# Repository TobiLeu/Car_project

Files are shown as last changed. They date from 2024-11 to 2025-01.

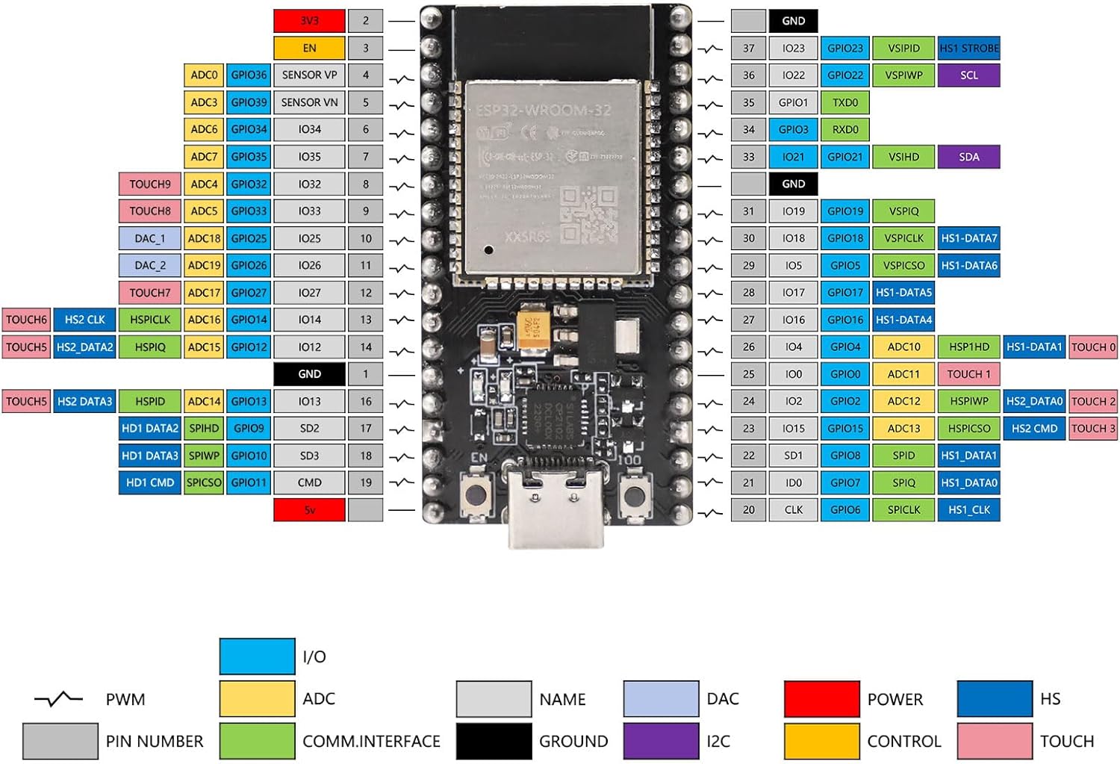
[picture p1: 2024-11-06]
Datenblätter/ESP32_Pinout.jpg

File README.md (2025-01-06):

Bei diesem Repository handelt es sich um ein Projekt für ein ferngesteuertes Auto:

Ein Video des Fahrzeugs ist im Repository vorhanden.
Programmierung ist mit Micropython erfolgt.
Es wurde ein Bausatz eines Kettenlaufwerks verwendet. Stattdessen kann mit dem Code im Repository auch ein Fahrzeug verwendet werden, das über Einzelansteuerung des beiden Fahrzeugseiten lenkt.

Beschreibung:

Auto:
Es wurde ein Bausatz eines Kettenlaufwerks verwendet, im Internet unter den Namen T101 oder TP101 zu finden. Ein Datenblatt für den Bausatz ist nicht erhältlich.
Der verwendete Bausatz hat 2 12V DC Motoren. Diese werden über eine H-Brücke versorgt. Als Batterie wurden alte Lithium Akkus verwendet.
Die Karosserie wurde mit einem 3D-Drucker hergestellt, Modell im Repository.
Es wurde ein ESP32 verwendet. Dieser steuert das Auto und erhält die Steuersignale von einem zweiten ESP32 im Controller, das ESPNow Modul wurde für die Datenübertragung verwendet.
Die Beleuchtung des Autos erfolgt mit LED's, die über den Controller an bzw. ausschaltbar sind.

Controller:
Der Controller für die Fernsteuerung wurde selbst gebaut. Hierzu wurde eine Abzweigdose verwendet, in die ein ESP32 eingebaut wurde. Der ESP32 wird mit einer 5V-Powerbank versorgt.
Der Controller hat 2 Joysticks mit Tasterfunktion, die je eine Kette des Fahrzeugs steuern. Die Tasterfunktion eines Joysticks wird für die An-/Ausschaltung des Fahrzeuglichts verwendet.
Zusätzlich ist im Controller ein 5V LCD-Display verbaut worden, Datenblatt nicht vorhanden. Das Display die Geschwindigkeit jeder einzelnen Kette in Prozent an.
Ein Start des Controllers führt zum Reset des Microcontrollers des Autos.

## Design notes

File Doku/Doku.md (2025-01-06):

# Dokumentation <TEAMNAME>

**Mitglieder:**
- Annika Hoffmanns
- Christian Löhner
- Tobias Leuthel

## Woche 1 (28.10- 03.11.2024)

### Aktivitäten:
- Zusammenbauen des Kettenradsatzes, Austesten an 9V Batterieblock

### Probleme und Lösungen:
- ChatGPT ist nicht hilfreich. Konkretere prompts sind nötig.

### Code:
- Siehe git history.

### Quellen:

## Woche 2 ( 04. - 10.11.2024)

### Aktivitäten:
- Informationen über ESP Now gesammelt
 - Mac Adressen ausgelesen (Annika) 
-   1: MAC-Adresse des ESP32: 88:13:bf:6f:c1:9c   (Controller - Sender) 
-   2: MAC-Adresse des ESP32: ac:15:18:e9:8c:7c   (Reserve ESP)
-   3: MAC-Adresse des ESP32: 88:13:bf:6f:b9:bc   (Auto - Empfänger) 

 - ESP 32 Treiber heruntergeladen und geflasht (Tobi) 
 - Funktion für die Vorwärtsfahrt erstellt (Christian) 

### Quellen:
 - https://wolles-elektronikkiste.de/esp-now    ( Auslesen der Mac-Adresse) 

## Woche 3 ( 11. - 17.11.2024)

### Aktivitäten:
- Informationen über ESP Now gesammelt (Tobi)
    -Chat GPT über biderektionale Verbindung zweier ESP's gefragt:
    - Probleme: esp.init() wird nicht gefunden
                OSError wird gemeldet: OSError: (-12389, 'ESP_ERR_ESPNOW_NOT_INIT')
                bisher noch keine Lösung gefunden

- Code für Fahrfunktionen schreiben (Chris)
 -Joysticks auf den ESP Auto montiert (Annika)
 -Fahrbetrieb getestet (Annika, Chris)
 -Verdrahtung Auto (Annika)
 
-Über Schaltplanzeichnen informiert (Chris)

### Quellen:
 - https://chatgpt.com/g/g-cKXjWStaE-python/c/6719f789-da14-800c-9771-9de5a383086b ; Link Chatgpt
 - https://docs.micropython.org/en/latest/library/espnow.html

## Woche 4 ( 18. - 24.11.2024)

### Aktivitäten:
- Code für Controller geschrieben und angepasst (Tobi, Annika)
    -Umwandlung von Byte-Signal
    -Codevorlage von mycropython.org angepasst

- Code Fahrfunktion überarbeitet (Chris, Tobi):
    -lineare Transformation Probleme behoben
    -Umwandlung vom Sendersignal von 16 bit auf 10 bit von Chat GPT Funktion schreiben lassen

- Abzweigdose für Controller vorbereitet (Annika)

 -Fahrbetrieb getestet (Annika, Chris, Tobi)

### Quellen:
 - https://chatgpt.com/g/g-cKXjWStaE-python/c/6719f789-da14-800c-9771-9de5a383086b
 - https://docs.micropython.org/en/latest/library/espnow.html

## Woche 5 ( 25.11 - 01.12.2024)

### Aktivitäten:
- Controller
    - Öffnungen mit Dremel ausfräsen (Annika)
    - Displayhalterung gedruckt (Chris)
    - Controller bis auf Ein-/Ausschalter mechanisch fertiggestellt (Annika)

- Code Auto (Tobi)
    -Sendefunktion überarbeitet: 
        Problem, dass Steuerung nicht funktioniert, wenn der Controller nach dem Auto eingeschaltet wird
        Lösung: reboot Befehl an Auto ESP senden, wenn der Controller ESP eingeschaltet wird
    
- Code Controller (Annika)
    - Tasterbefehl einlesen und an Auto senden

- Spannungsversorgung Auto, mit Festspannungsregler; 2x 9V Blöcke in Reihe auf 12V regeln (Chris)
    - Die 9 V Blöcke, aufladbar per USB-C, haben eine Laderegelung, die abschaltet. -> 9V NiMh Akkus verwenden

- Schaltung für LED's Autobeleuchtung (Tobi)
    - LED's direkt über den ESP ansteuern: hat nicht funktioniert, vermutlich zu viel Strom -> extra Schaltung nötig

### Quellen:
 LED Flussspannungen: https://www.mikrocontroller.net/articles/LED#Flu%C3%9Fspannung

## Woche 6 ( 02.12 - 08.12.2024)

### Aktivitäten:

- Code Auto (Chris)
    - Pinout für Beleuchtung programmiert
    
- Controller (Annika)
    - Taster verdrahtet

- Spannungsversorgung (Chris, Annika):
    - Controller: Senden funktioniert nicht mit 3,3V -> 5V Powerbank verwenden
    - 24V Batterieblock demontiert und einzelne Zellen verwenden (14V)

- Schaltung für LED's Autobeleuchtung (Tobi)
    - Schaltung berechnet, verdrahtet und getestet

### Quellen:
 LED Flussspannungen: https://www.mikrocontroller.net/articles/LED#Flu%C3%9Fspannung

## Woche 7 ( 09.12 - 15.12.2024)

### Aktivitäten:
    
- Controller
    - Code für das LCD Display geschrieben: Umrechnungsfunktionen von Code Auto benutzt (Tobi)
    - Ein/Aus Schalter eingebaut (Annika)

- Hardware Auto auf Lochrasterplatine gelötet (Chris)

- Karosserie gedruckt (Chris)

### Quellen:
 https://chatgpt.com/g/g-cKXjWStaE-python/c/6719f789-da14-800c-9771-9de5a383086b
 Link Modell T1 Bus: https://www.printables.com/model/35314-modular-vw-bus-container

## Woche 8 ( 16.12 - 22.12.2024)

### Aktivitäten:
    
- Controller 
    - Hardware auf Lochrasterplatine löten (Chris)
    - Display einbinden (Chris, Tobi, Annika)

- Karosserie:
    - Einbau der LED's und Magnete für Dachhalterung (Annika, Chris)
    - Aufkleber drucken + bekleben (Annika)

### Quellen:
https://chatgpt.com/g/g-cKXjWStaE-python/c/6719f789-da14-800c-9771-9de5a383086b

## Woche 9 + 10 ( 23.12.2024 - 05.01.2025)

### Aktivitäten:
    
- Videodreh (Annika)

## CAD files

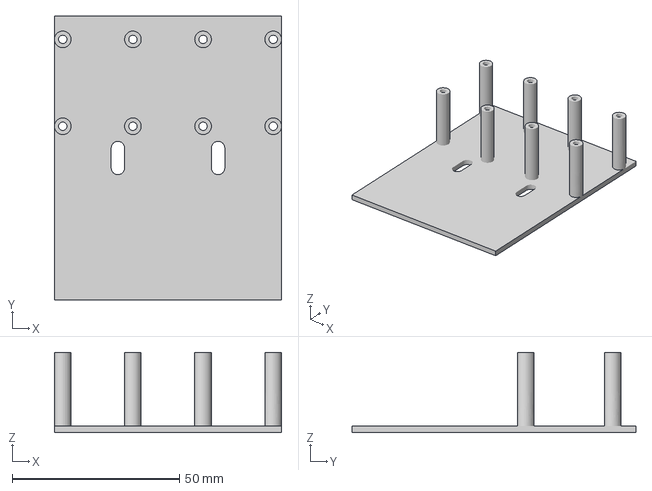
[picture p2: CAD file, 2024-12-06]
Datenblätter/Grundplatte.3mf
68.0 x 85.0 x 24.0 mm

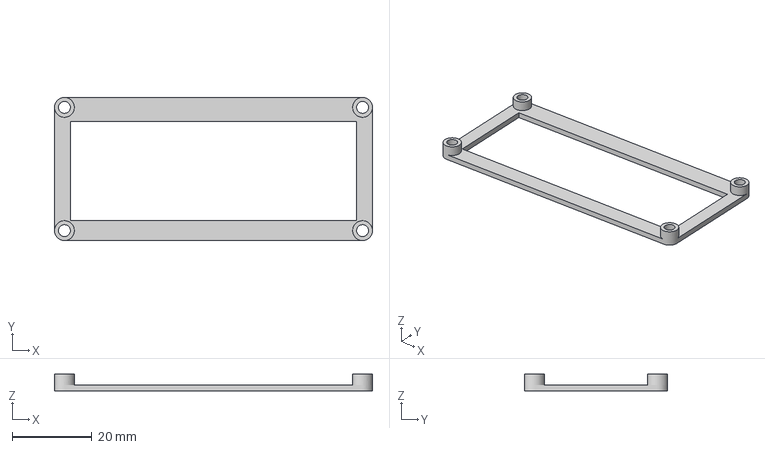
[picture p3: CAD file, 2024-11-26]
Datenblätter/Halterung.3mf
80.0 x 36.0 x 4.20 mm

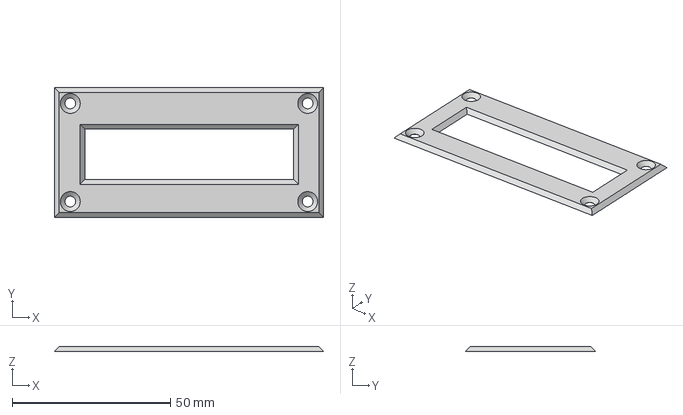
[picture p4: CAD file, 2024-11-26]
Datenblätter/Abdeckung.3mf
85.0 x 41.0 x 1.50 mm

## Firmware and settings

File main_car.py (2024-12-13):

from machine import Pin, ADC, PWM
import machine
import time
import network 
import espnow


# MAC-Adresse des ESP32: 88:13:bf:6f:b9:bc

#Setup PINS

motor_1_IN1 = Pin(22, Pin.OUT)
motor_1_IN2 = Pin(23, Pin.OUT)
motor_1_pwm = PWM(Pin(32), freq=250, duty=0)
motor_2_IN3 = Pin(27, Pin.OUT)
motor_2_IN4 = Pin(14, Pin.OUT)
motor_2_pwm = PWM(Pin(12), freq=250, duty = 0)
light = Pin(15, Pin.OUT)

#Setup WLAN
wlan = network.WLAN(network.STA_IF)
wlan.active(True)
wlan.disconnect()   # Because ESP8266 auto-connects to last Access Point

#ESP Now Setup
e = espnow.ESPNow()
e.active(True)

#ADC 
death_zone_upper_limit = 530
death_zone_lower_limt = 400
pwm_start = 256
pwm_end = 1023




# 16bit Eingang zu 10 bit konvertieren
def convert_16bit_to_10bit(value_16bit):
    
    if not (0 <= value_16bit <= 65535):
        raise ValueError("Die Eingabewert muss zwischen 0 und 65535 liegen.")
    
    # Skalieren des 16-Bit-Wertes in den Bereich einer 10-Bit-Zahl
    value_10bit = int((value_16bit / 65535) * 1023)
    
    return value_10bit


# PWM signal for forward drive
def map_range_forward(value, in_min, in_max, out_min, out_max):
    """
    Rechnet einen Wert aus einem Bereich in einen anderen Bereich um.

    :param value: Der Eingabewert, der umgerechnet werden soll.
    :param in_min: Untere Grenze des Eingabebereichs.
    :param in_max: Obere Grenze des Eingabebereichs.
    :param out_min: Untere Grenze des Zielbereichs.
    :param out_max: Obere Grenze des Zielbereichs.
    :return: Der umgerechnete Wert im Zielbereich.
    """
    return (value - in_min) * (out_max - out_min) // (in_max - in_min) + out_min



def map_range_backward(value, in_min, in_max, out_min, out_max):
    """
    Rechnet einen Wert aus einem Bereich in einen anderen Bereich um.
    :param value: Der Eingabewert, der umgerechnet werden soll.
    :param in_min: Untere Grenze des Eingabebereichs.
    :param in_max: Obere Grenze des Eingabebereichs.
    :param out_min: Untere Grenze des Zielbereichs.
    :param out_max: Obere Grenze des Zielbereichs.
    :return: Der umgerechnete Wert im Zielbereich.
    """
    return (value - in_min) * (out_max - out_min) // (in_max - in_min) + out_min


def left_track (analog_In_l):
    if analog_In_l > death_zone_upper_limit :
        motor_1_IN1.on()
        motor_1_IN2.off()
        motor_1_pwm.duty(map_range_forward(analog_In_l, death_zone_upper_limit, 1023, pwm_start, pwm_end))
    
    elif analog_In_l < death_zone_lower_limt :
        motor_1_IN1.off()  
        motor_1_IN2.on()
        motor_1_pwm.duty(map_range_backward(analog_In_l,death_zone_lower_limt, 0, pwm_start, pwm_end))
    
    else:
        motor_1_IN1.off()
        motor_1_IN2.off()
        motor_1_pwm.duty(0)

# Steuerung rechte Kette

def right_track(analog_In_r):
    if analog_In_r > death_zone_upper_limit:
        motor_2_IN3.on()
        motor_2_IN4.off()
        motor_2_pwm.duty(map_range_forward(analog_In_r, death_zone_upper_limit, 1023, pwm_start, pwm_end))

    elif analog_In_r < death_zone_lower_limt :
        motor_2_IN3.off()  
        motor_2_IN4.on()
        motor_2_pwm.duty(map_range_backward(analog_In_r, death_zone_lower_limt, 0, pwm_start, pwm_end))
    
    else:
        motor_2_IN3.off()
        motor_2_IN4.off()
        motor_2_pwm.duty(0)

# Hauptschleife  
while True:
    host, msg = e.recv()
    if msg:  #msg == None if timeout in recv()
        print(msg)
        msg =str(msg)
        msg = msg.lstrip("b'")
        msg = msg.rstrip("'")
        values = msg.split(",")
        value1 = int(values[0])
        value2 = int(values[1])
        value3 = int(values[2])
        value4 = int(values[3])
        value1 = convert_16bit_to_10bit(value1)
        value2 = convert_16bit_to_10bit(value2)

        if value3 == 1:
            print("rebooting")
            machine.reset()
            
        if value4 == 1:
            print("light")
            light.on()
        else:
            light.off()

        left_track(value1)
        right_track(value2)
        time.sleep(0.001)

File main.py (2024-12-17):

import machine
import time
import network
import espnow
from machine import ADC,Pin
from lcd1602 import LCD1602
'''
# WLAN-Station (Client) Schnittstelle initialisieren
wlan = network.WLAN(network.STA_IF)
wlan.active(True)

# MAC-Adresse abrufen
mac_address = wlan.config('mac')
mac_address_str = ':'.join(['{:02x}'.format(b) for b in mac_address])

# MAC-Adresse ausgeben
print("MAC-Adresse des ESP32:", mac_address_str)
'''
### Datenübertragung initialisieren

# A WLAN interface must be active to send()/recv()
sta = network.WLAN(network.STA_IF)  # Or network.AP_IF
sta.active(True)
sta.disconnect()      

e = espnow.ESPNow()
e.active(True)
peer = b'\x88\x13\xbf\x6f\xb9\xbc'   # MAC address of receiver  88:13:bf:6f:b9:bc
e.add_peer(peer)      # Must add_peer() before send()


# Pins definieren

adc2 = ADC(36)
adc2.atten(ADC.ATTN_11DB) #Messbereich auf 
adc1 = ADC(39)
adc1.atten(ADC.ATTN_11DB)

button = Pin(25, Pin.IN, Pin.PULL_UP)
light = 0


########################################################################################## 
    #LCD Display
 
#ADC 
death_zone_upper_limit = 530
death_zone_lower_limt = 400
pwm_start = 256
pwm_end = 1023

### Berechnungsfunktionen für die Displayanzeige

# 16bit Eingang zu 10 bit konvertieren
def convert_16bit_to_10bit(value_16bit):
    
    if not (0 <= value_16bit <= 65535):
        raise ValueError("Die Eingabewert muss zwischen 0 und 65535 liegen.")
    
    # Skalieren des 16-Bit-Wertes in den Bereich einer 10-Bit-Zahl
    value_10bit = int((value_16bit / 65535) * 1023)
    
    return value_10bit

# PWM signal for forward drive
def map_range_forward(value, in_min, in_max, out_min, out_max):
    """
    Rechnet einen Wert aus einem Bereich in einen anderen Bereich um.

    :param value: Der Eingabewert, der umgerechnet werden soll.
    :param in_min: Untere Grenze des Eingabebereichs.
    :param in_max: Obere Grenze des Eingabebereichs.
    :param out_min: Untere Grenze des Zielbereichs.
    :param out_max: Obere Grenze des Zielbereichs.
    :return: Der umgerechnete Wert im Zielbereich.
    """
    return (value - in_min) * (out_max - out_min) // (in_max - in_min) + out_min



def map_range_backward(value, in_min, in_max, out_min, out_max):
    """
    Rechnet einen Wert aus einem Bereich in einen anderen Bereich um.
    :param value: Der Eingabewert, der umgerechnet werden soll.
    :param in_min: Untere Grenze des Eingabebereichs.
    :param in_max: Obere Grenze des Eingabebereichs.
    :param out_min: Untere Grenze des Zielbereichs.
    :param out_max: Obere Grenze des Zielbereichs.
    :return: Der umgerechnete Wert im Zielbereich.
    """
    return (value - in_min) * (out_max - out_min) // (in_max - in_min) + out_min

def left_track (analog_In_l):
    if analog_In_l > death_zone_upper_limit :
        
        return map_range_forward(analog_In_l, death_zone_upper_limit, 1023, pwm_start, pwm_end)
    
    elif analog_In_l < death_zone_lower_limt :
        
        return map_range_backward(analog_In_l,death_zone_lower_limt, 0, pwm_start, pwm_end)
    
    else:    
        return 0

def map_to_percentage(value, start=pwm_start, end=pwm_end):
    """
    Wandelt einen Wert aus dem Bereich [256, 1023] in einen Prozentsatz [1, 100] um.
    Wenn der Wert 0 ist, wird 0% zurückgegeben.
    
    :param value: Der Eingabewert, der in Prozent umgerechnet werden soll.
    :param start: Der Anfangswert des Bereichs (256 entspricht 1%).
    :param end: Der Endwert des Bereichs (1023 entspricht 100%).
    :return: Der Wert als Prozentsatz (zwischen 0 und 100).
    """
    if value == 0:
        return 0  # 0 ergibt 0%
    

    # Prozentwert berechnen
    percentage = (value - start) * (100 - 1) / (end - start) + 1
    return round(percentage)
   

# LCD initialisieren 
lcd = LCD1602(rs=4, e=5, d4=16, d5=17, d6=18, d7=19) # Nummern in der Funktion entsprechen den verwendeten Pins

######################################################################################################


# ESP am Auto rebooten: 5 Sekunden warten auf Reboot
msg= b'30000,30000,1,0'
e.send(peer, msg, True)
print(msg)
time.sleep(5)

######################################################################################################

#Programmschleife

while True:
    val1 = adc1.read_u16()
    val2 = adc2.read_u16()

    #Umrechnen der Eingangswerte für das Display
    value_left_joystick = convert_16bit_to_10bit(val1)
    value_left_display = left_track(value_left_joystick) 
    
    value_right_joystick = convert_16bit_to_10bit(val2)
    value_right_display = left_track(value_right_joystick) 

    Displaywert_Kette_links = map_to_percentage(value_left_display)
    Diplaywert_Kette_rechts = map_to_percentage(value_right_display)

    # Anzeige Display
    lcd.clear()
    lcd.write(0, 0, f"Links     Rechts")
    lcd.write(1, 0, f"{Displaywert_Kette_links}%        {Diplaywert_Kette_rechts}%")
    

    # Taster prüfen (LOW = gedrückt)
    if button.value() == 0:
        while button.value() == 0:
            pass  
        
        # LED-Zustand umschalten
        light = 1 - light
   
    #Erstellen und Senden der Nachricht an den ESP Auto
    msg = ",".join([str(val1),str(val2),"0",str(light)])
    e.send(peer, msg , True)

    time.sleep_ms(50)

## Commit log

2024-10-29 Code LED Schaltung für WLAN-Verbindungstest
2024-11-06 Datenblatt für H-Brücke und Pinout für ESP hinzugefügt Quellen.txt hizugefügt, Doku-ordner hizugefügt
2024-11-19 Ändern der Senden Funktion
2024-11-26 Code Verbessern der Sendefunktion
2024-11-26 Datenblätter für Spannungswandler und 3D Dateien für 3D Druck hinzugefügt
    [Abdeckung.3mf, Halterung.3mf]
2024-11-29 main_car Auslesen des Lichts eingebaut, 3mf datei für Grundplatte hinzugefügt
    [Grundplatte.3mf]
2024-12-06 Ausgang für LED in CAr-code eingefügt
2024-12-07 Update main_car.py
    Pin für Light angepasst
2024-12-17 Einbinden des Displayin den Controller
2024-12-17 Ändern des lcd.py moduls
